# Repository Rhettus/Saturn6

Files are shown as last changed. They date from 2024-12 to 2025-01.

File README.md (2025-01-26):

# Saturn 6 
Saturn 6: a compact 10” minilab that hosts 5xRaspberry Pi's and an ARM based NAS.

## Whats new:

**01/26/2024** - Modification to the RPi cluster holder. This is now 1 piece which helps with tolerances and fitment into the rack. No need for threaded rods anymore. The rear has been opened up to allow more airflow. Mounts for 3x70mm fans have been included to draw air through the front, over the Pi's and out the rear. Mine are controlled via a ESP32 microcontroller hooked up to Home Assistant.

## Printed parts

All chassis parts are printed in PETG

All faceplates are printed in PLA (Matte in my case)

## License

This project is licensed under the [Creative Commons Attribution-NonCommercial 4.0 International (CC BY-NC 4.0)](https://creativecommons.org/licenses/by-nc/4.0/) license.

You are free to:  
- **Share**: Copy and redistribute the material in any medium or format.  
- **Adapt**: Remix, transform, and build upon the material.  

Under the following terms:  
- **Attribution**: You must give appropriate credit, provide a link to the license, and indicate if changes were made.  
- **NonCommercial**: You may not use the material for commercial purposes.  
- **No Additional Restrictions**: You may not apply legal terms or technological measures that legally restrict others from doing anything the license permits.  

A copy of the full license text can be found [here](https://creativecommons.org/licenses/by-nc/4.0/legalcode).

If you use or remix these files, I'd love to hear about it! Feel free to share your projects or modifications.

## BOM
BOM for Saturn 6 project

Parts for build v1.1
 - [Slim Cat6 patch cables](https://a.co/d/a7xnncM)
 - [140mm fan for exhaust](https://a.co/d/3VLQnNa)
 - [2x 2.5Gbe PoE switches](https://a.co/d/4PgA6Y8) with SFP+ - Get the managed version
 - [0.3m DAC cable](https://a.co/d/iWrGbuD)
 - [2020 corner joints](https://a.co/d/eAyFSsW)
 - [Din rails](https://a.co/d/hCQvD7X)
 - [38mm Compressor feet](https://a.co/d/a7xnncM)
 - [600mm 2020 Extrusion](https://a.co/d/5f3lkJL) 4x400mm and 8x214mm
 - [6 outlet PDU](https://www.aliexpress.us/item/3256805777681738.html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)
 - [QuickPort F-Type Adapter](https://a.co/d/gwulnIx) - for rear skirt internet connection
 - M5 screws - button head for the front
 - [M5 T-nuts](https://a.co/d/aCP52xv) (lots)
 - M3 screws for top panel clips, panel clips and the switch chassis ears
 - M3 Heat set inserts for switch ears and DIN brackets
 - 17x Cat 6a keystone jacks 

Not needed in v1.1
- ~~[Threaded M4 rods](https://a.co/d/84yPzoR) to hold the Pi cluster together. These will need to be cut down.~~
 - ~~M4 Nuts~~

Printed parts not included
 - 16x[ Voron panel clips](https://www.printables.com/model/702768-kit-for-removable-panelsdoors-for-voron-v2trident-/files). 
 - 4x[Bottom Corner Bracket](https://www.printables.com/model/702768-kit-for-removable-panelsdoors-for-voron-v2trident-/files) - 1mm Foam Tape - Use for top panel
 - 4x[Compact ZeroG Bracket Mod](https://www.printables.com/model/519670-compact-zerog-din-bracket-mod)

## Known issues:

- The RPi holders that fit the PoE & NVMe hat block off USB power port. Not an issue for me
- ~~The width of the RPi holders is too wide to fit the threaded screw between the extrusions. Need to trim a couple of mm off each holder and redo the ears. I assembled in the rack.~~

Work in progress

## Attributions
Thanks to the wonderful creators and licensing under CC. These are the 3D files I either used, or remixed for Saturn 6 which were not my own                                                                                                 
| Part | Creator | Link | Modifications |
| --- | --- | --- | --- |
| Fan cover | [StoniXX](https://www.thingiverse.com/StoniXX) | https://www.thingiverse.com/thing:5488632 | Removed bottom bracket |
| 2020 Handles | [Andreas_34203](https://www.printables.com/@Andreas_34203) | https://www.printables.com/model/10745-handle-for-2020-aluminum-extrusion | - |
| Patch panel - front | [Weinachten](https://www.thingiverse.com/Weinachten) | https://www.thingiverse.com/thing:5992963/files | Removed some of the strengthening and changed to standard front plate design |
| Patch panel - rear | [Weinachten](https://www.thingiverse.com/Weinachten) | https://www.thingiverse.com/thing:5992963/files | Reduce to 7 ports to give room for PDU |
| RPI cluster | [russross](https://www.thingiverse.com/russross) | https://www.thingiverse.com/thing:4078710 | Made wider to accommodate the PoE Hat (with GPIO pins) |
| Voron panel latches | [Victor Mateus Oliveira](https://www.printables.com/@VictorMateusO_607762) | https://www.printables.com/model/702768-kit-for-removable-panelsdoors-for-voron-v2trident-/files | - |
| Voron top panel corners | [Victor Mateus Oliveira](https://www.printables.com/@VictorMateusO_607762) | https://www.printables.com/model/702768-kit-for-removable-panelsdoors-for-voron-v2trident-/files | - |
| Keystone jack | [PR1NT3D](https://www.thingiverse.com/PR1NT3D) | https://www.thingiverse.com/thing:5902371 | Integrated into NAS front panel and and rear skirt |
| CM3588 NAS case | [@Fuzzler_1944079](https://www.printables.com/@Fuzzler_1944079) | https://www.printables.com/model/826870-friendlyelec-cm3588-nas-case-for-10-rack | Flipped the mount, added led light holes, keystone for rj45, room to install the keystone jack. Replace front panel with Saturn 6 standard |
| Unifi USG | [dewenni](https://www.thingiverse.com/dewenni) | https://www.thingiverse.com/thing:6145449 | - |
| Din drop downs | [----------------------------------------](https://www.printables.com/@_172228) | https://www.printables.com/model/519670-compact-zerog-din-bracket-mod | Extended 5mm lower to have room for xfinity router |
| Mercury One 38mm Feet | [ZeroGDesign](https://github.com/ZeroGDesign/docs/commits?author=ZeroGDesign) | https://github.com/ZeroGDesign/docs/blob/gh-pages/docs/assets/stl/electronics_enclosure/skirt/SK_FT_38mm_PowerSW.stl | - |
| 7 ethernet cable holder | [luon45](https://www.thingiverse.com/Gluon45) | https://www.thingiverse.com/thing:4159459/files | Printed at 110% to support CAT6a |
| USB plug for Pi labels  | [mfischer79](https://www.printables.com/@mfischer79) | https://www.printables.com/model/404578-usb-a-dust-coverplugcap | |
| Ethernet cable labels | [flol3622](https://www.printables.com/@flol3622) | [https://www.printables.com/model/72401-ethernet-cable-label](https://www.printables.com/model/72401-ethernet-cable-label) | Printed at 110% |
| S-II Unifi AP riser | [@NASA](https://www.myminifactory.com/users/NASA) | https://www.myminifactory.com/object/3d-print-saturn-v-rocket-stage-2-29288 | Used only 10mm of the top of stage II |

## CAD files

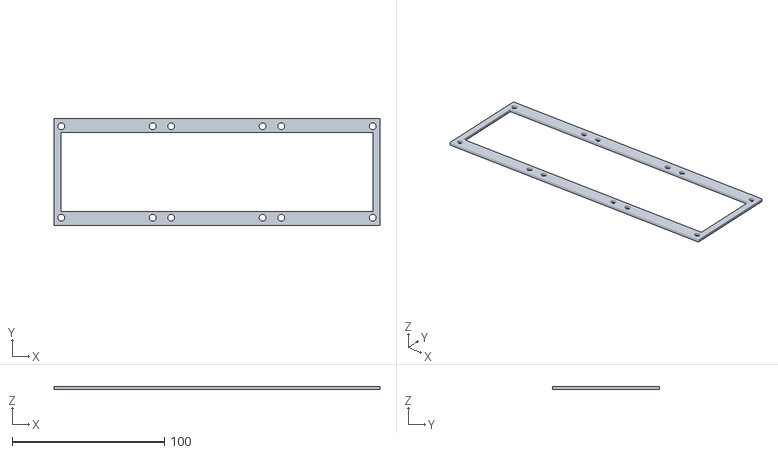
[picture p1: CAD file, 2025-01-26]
Chassis/Rpi_cluster-FanSpacer.stl
214.0 x 70.0 x 2.00

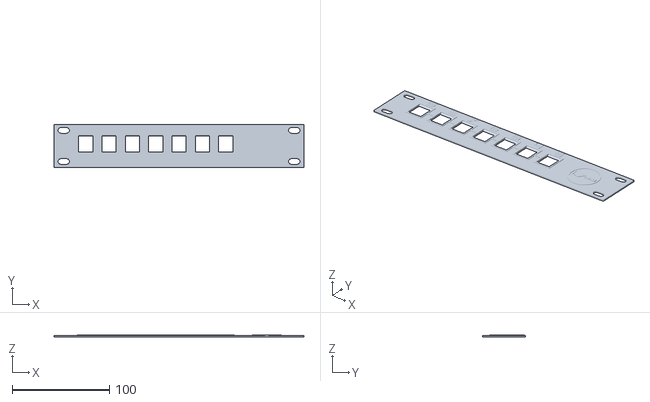
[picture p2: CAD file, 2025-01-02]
Face Plates/Rear_patch_panel_faceplate.stl
257.0 x 44.1 x 2.10

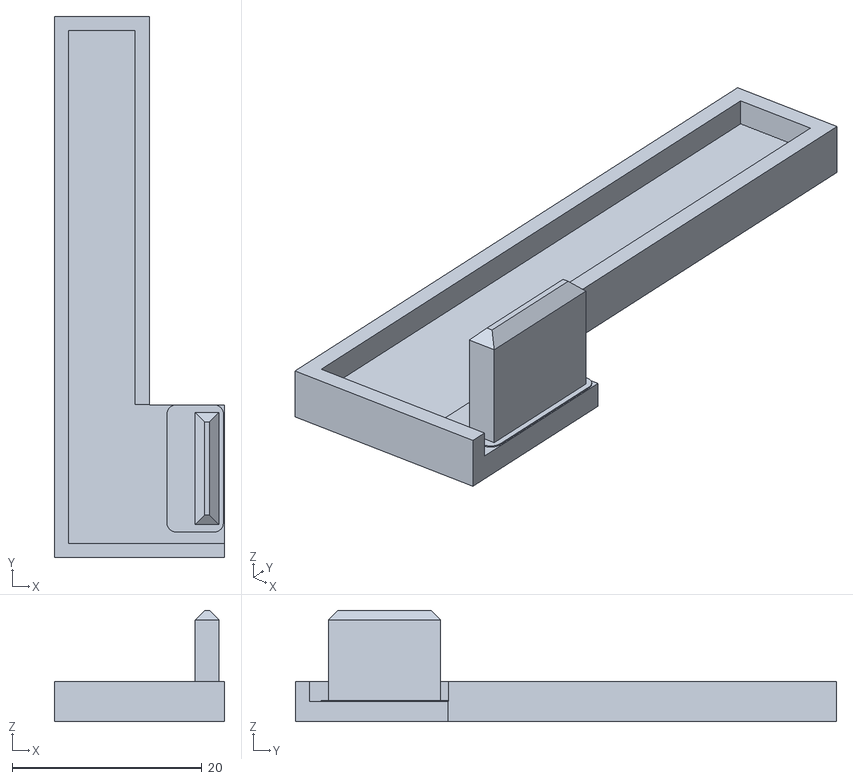
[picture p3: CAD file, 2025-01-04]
Other/Rpi - label holder.stl
17.9 x 57.0 x 11.7

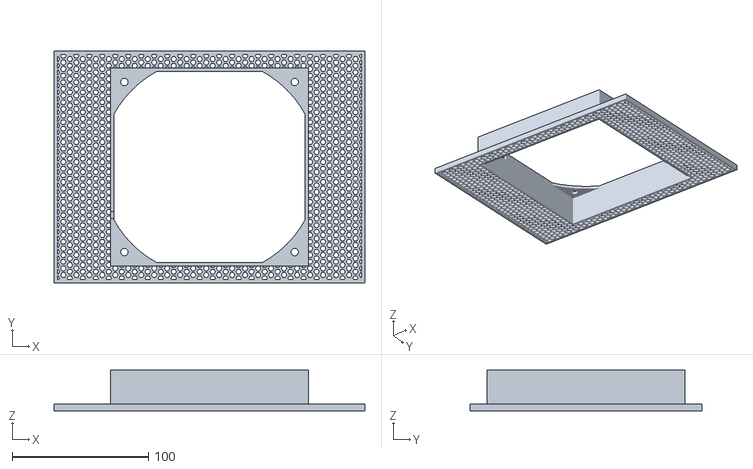
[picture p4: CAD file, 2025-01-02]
Panels/rear_panel-top(140mm fan).stl
228.0 x 170.0 x 30.0

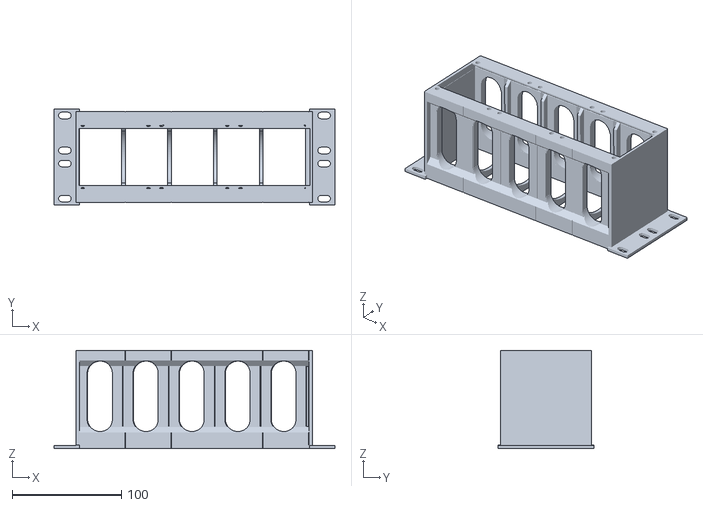
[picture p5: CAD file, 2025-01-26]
Chassis/Rpi_Cluster.stl
257.0 x 88.1 x 90.0

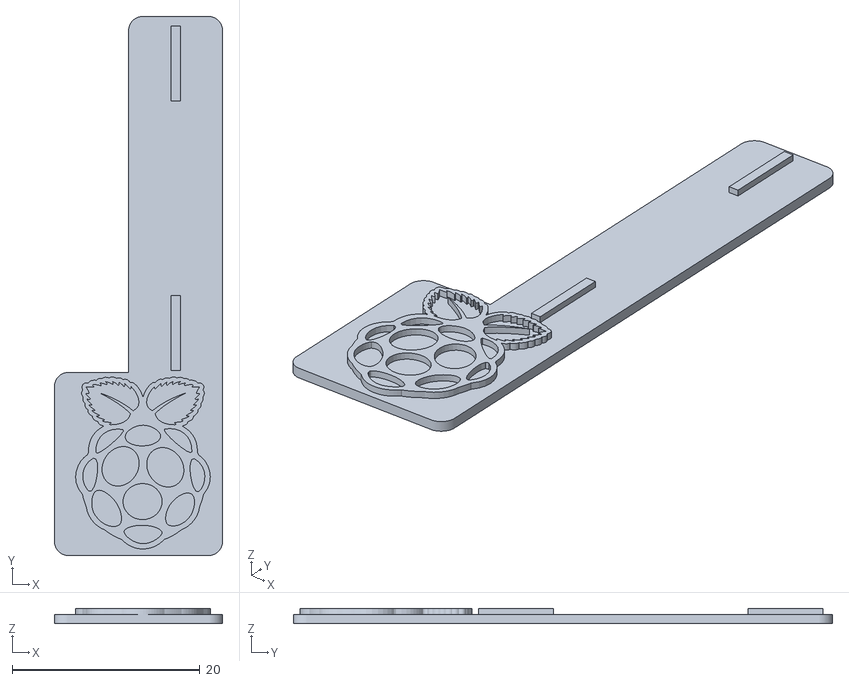
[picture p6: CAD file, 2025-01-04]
Other/Rpi - labels.stl
17.9 x 57.4 x 1.64

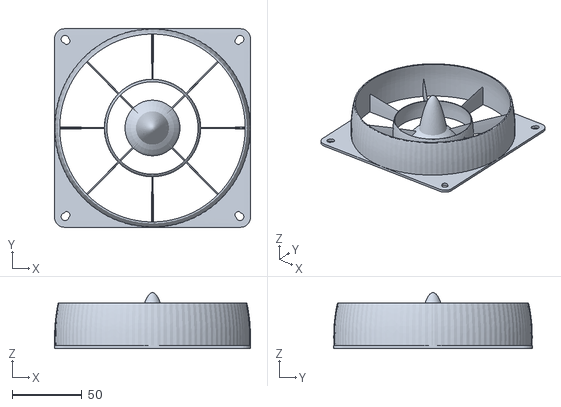
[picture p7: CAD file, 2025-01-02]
Panels/Saturn 6 - fan cover.stl
140.0 x 141.8 x 40.0

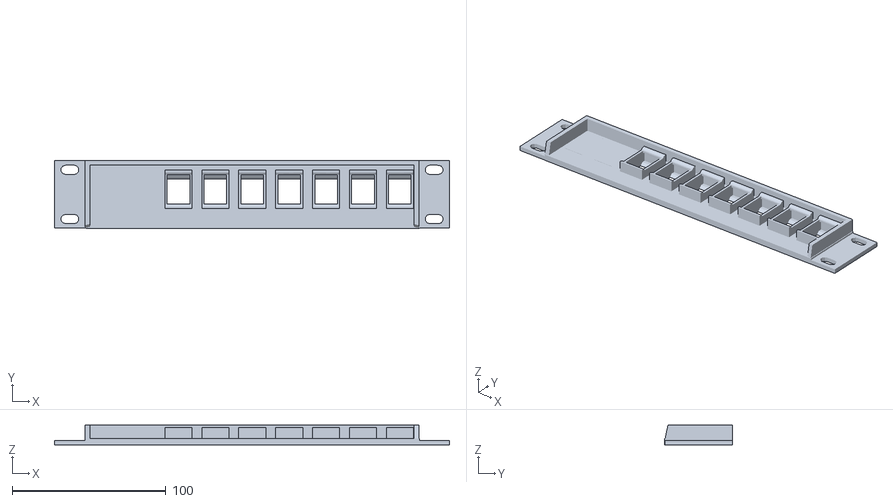
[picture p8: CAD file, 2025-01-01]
Chassis/rear-7port-patchpanel-keystone.stl
257.0 x 44.1 x 13.0

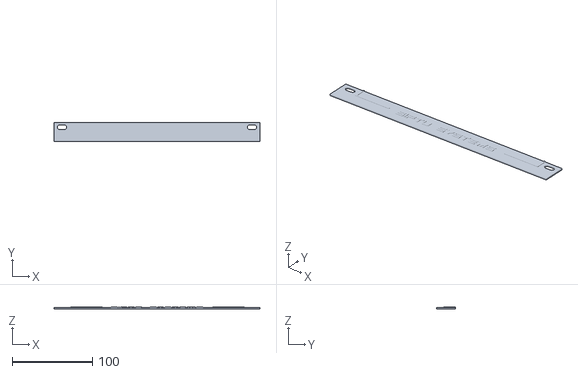
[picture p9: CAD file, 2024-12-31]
Face Plates/bottom-2020-cover.stl
257.0 x 24.0 x 2.10

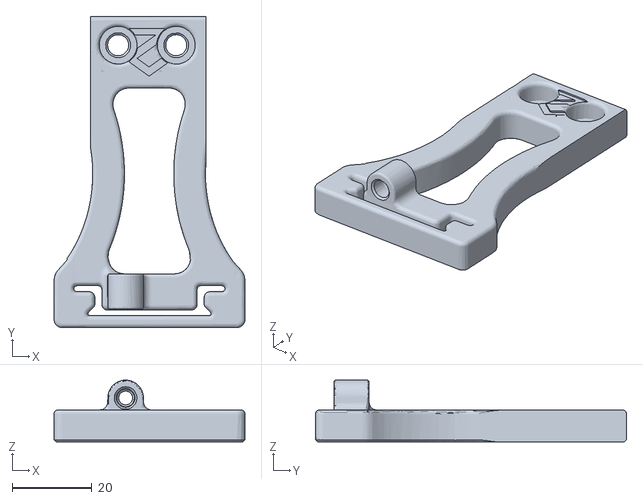
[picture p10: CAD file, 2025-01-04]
Other/din bracket.stl
48.0 x 78.2 x 15.5

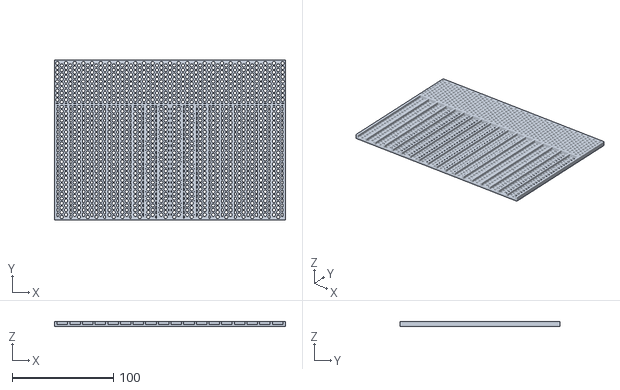
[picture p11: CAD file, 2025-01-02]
Panels/rear_panel-bottom.stl
228.0 x 158.0 x 5.00

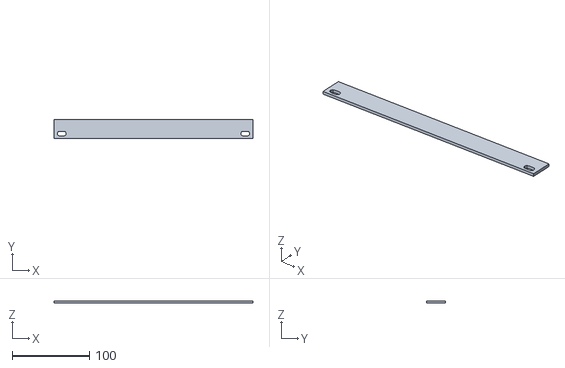
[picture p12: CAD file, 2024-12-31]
Chassis/Top-2020.stl
257.0 x 24.0 x 3.00

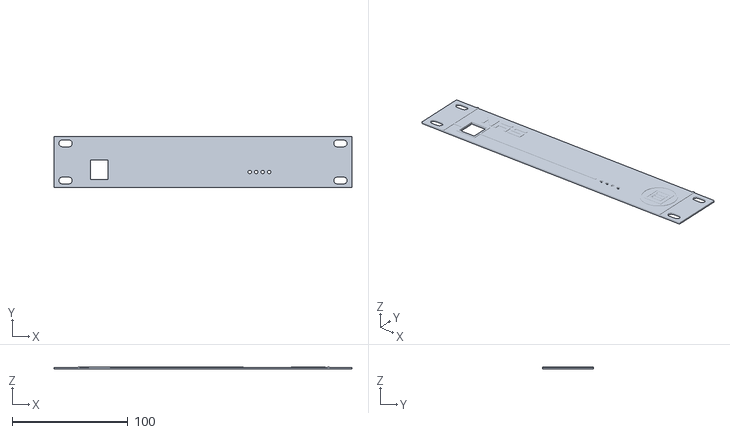
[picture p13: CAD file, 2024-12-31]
Face Plates/nas-faceplate.stl
257.0 x 44.1 x 2.10

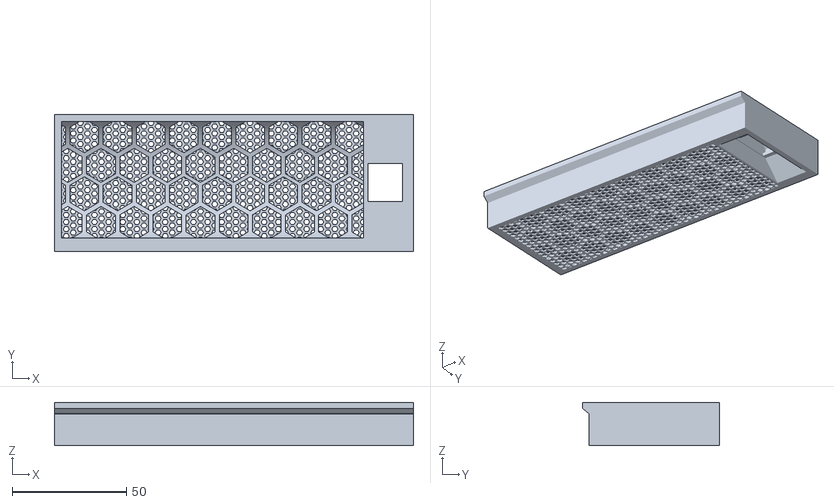
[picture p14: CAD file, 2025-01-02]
Other/158MM SKIRT-Rear.stl
157.0 x 60.0 x 19.0

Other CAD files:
Face Plates/Blank-faceplate.stl
Panels/side_panel-top.stl
Chassis/Blank-Saturn6.stl
Face Plates/fw-faceplate.stl
Chassis/bottom-2020.stl
Chassis/fw-unifi-usg.stl
Chassis/nas-cm3588.stl
Chassis/patchpanel-keystone.stl
Chassis/switch-chassis.stl
Chassis/switch-ears.stl
Face Plates/RPi_Cluster-faceplate.stl
Face Plates/Saturn6-faceplate.stl
Face Plates/patch_panel-faceplate.stl
Face Plates/sw1-faceplate.stl
Face Plates/sw2-faceplate.stl
Face Plates/top-2020-cover.stl
Other/158MM SKIRT.stl
Other/Latch M3x8.stl
Other/Top Panel Corner Bracket.3mf
Panels/Top Unifi Lite 6.stl
Panels/side_panel-bottom.stl
Panels/side_panel-middle.stl

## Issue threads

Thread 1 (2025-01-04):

BOM Links are the same

sithypenguin, 2025-01-04:
Looks like these BOM links are the same. The .3 DAC Cable appears to be correct, and everything starting with the 38mm compressor feet and below is correct as well.

Slim Cat6 patch cables https://a.co/d/a7xnncM
140mm fan for exhaust https://a.co/d/a7xnncM
Threaded M4 rods https://a.co/d/a7xnncM to hold the Pi cluster together
2x 2.5Gbe PoE switches https://a.co/d/a7xnncM
2020 corner joints https://a.co/d/a7xnncM
Din rails https://a.co/d/a7xnncM

I saw the post on reddit and immediately came here and saw the issue and wanted to make sure you were aware. Absolutely love the build and the whole idea as someone else who is a lover of space.

Rhettus, 2025-01-05:
I think I have fixed them. Let me know if anything else is missing/wrong. Happy to add them

Closed 2025-01-05.

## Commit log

2024-12-31 move sw-1 sfp+ port down 1mm
    [sw1-faceplate.stl]
2024-12-31 chassis components
    [Blank-Saturn6.stl, RPi-ears.stl, Top-2020.stl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]
2025-01-01 Rpi holders, rear patch panel
    [Blank-faceplate.stl, Rpi+Hat_2U-Rack.stl, rear-7port-patchpanel-keystone.stl]
2025-01-02 Rear panel parts
    [158MM SKIRT-Rear.stl, Rear_patch_panel_faceplate.stl, rear_panel-bottom.stl]
2025-01-02 Rear top panel and fan cover
    [Saturn 6 - fan cover.stl, rear_panel-top(140mm fan).stl]
2025-01-04 Updated DIN bracket
    [din bracket.stl]
2025-01-04 Add RPi labels
    [Rpi - label holder.stl, Rpi - labels.stl]
2025-01-04 Update to BOM
2025-01-04 Add to the attributions - ethernet cable labels
2025-01-05 Fix BOM links
2025-01-05 Yet more fixes to the BOM
2025-01-21 Update switch with correct URL (Managed vs non managed)
2025-01-26 Updates to Rpi cluster chassis
    [RPi-ears.stl, Rpi+Hat_2U-Rack.stl, Rpi_Cluster.stl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]
2025-01-26 Remove switch PDF 2G08110GSM_Web_Manual
